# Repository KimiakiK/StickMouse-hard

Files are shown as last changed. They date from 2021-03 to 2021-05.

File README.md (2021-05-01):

# Stick Mouse
[Software](https://github.com/KimiakiK/StickMouse-soft)

# Features
- ジョイスティックと静音スイッチを備えたスティック型のマウス
- マウスポインタの移動とスクロールをジョイスティックで操作（ジョイスティック押し込みで切り替え）
- 左クリックと右クリック

# Major Components  
- STM32F042K6
- Joystick
- Kailh ミュートマイクロスイッチ

# Photos
Stick Mouse V1.1
Stick Mouse example

## PCB
- V1.1
PCB V1.1
- V1.0
PCB V1.0

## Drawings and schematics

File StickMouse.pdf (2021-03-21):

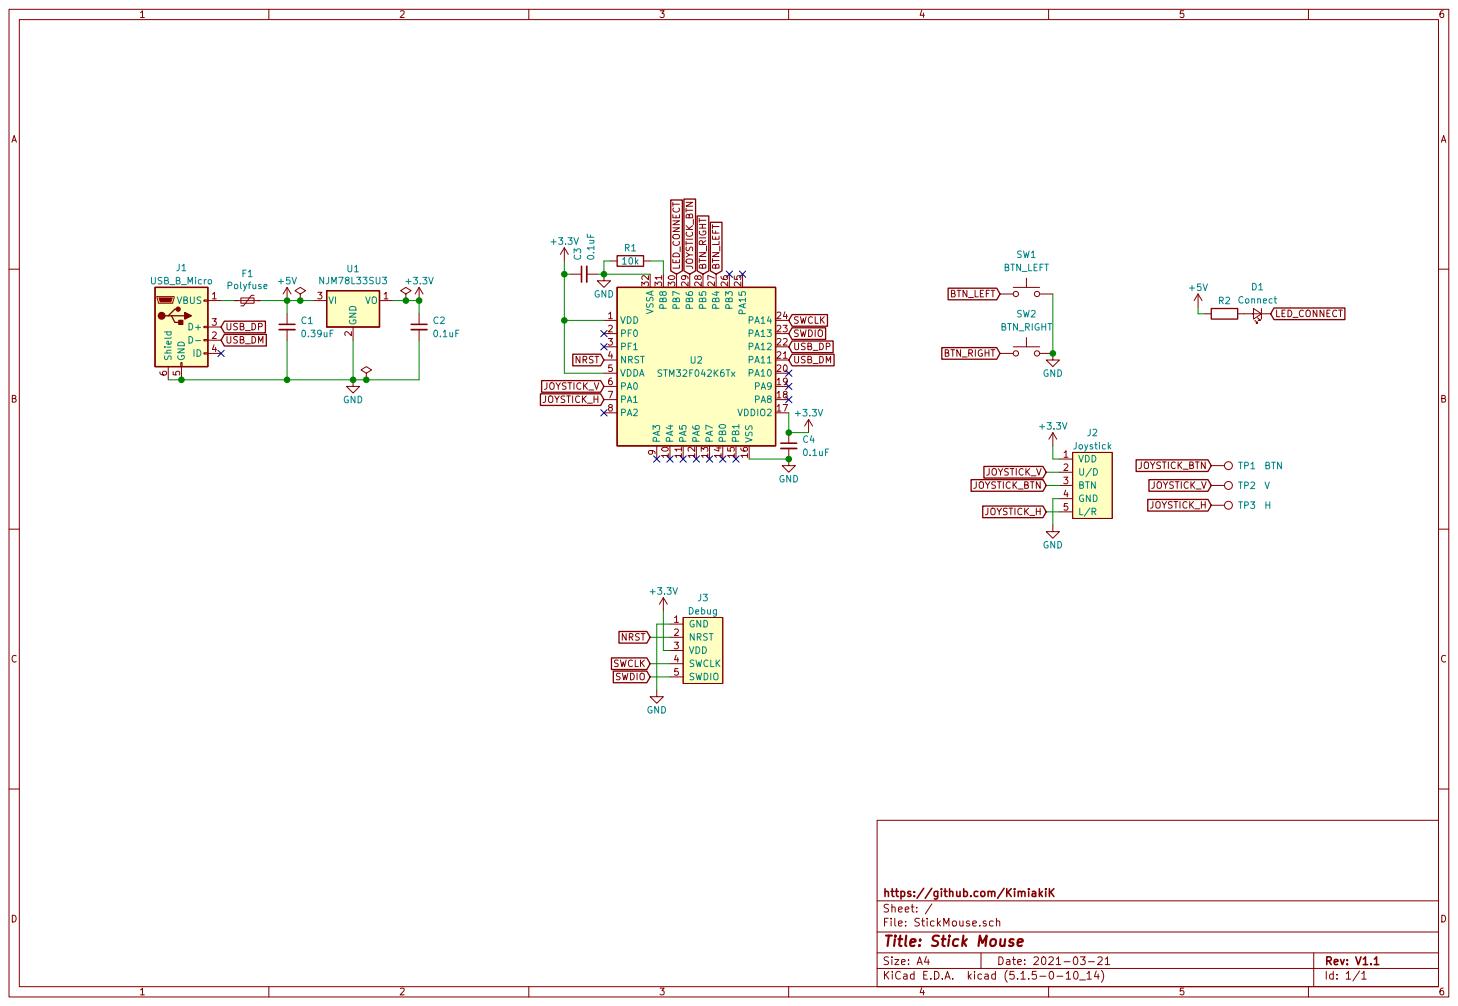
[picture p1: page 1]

File: StickMouse.sch Sheet: / https://github.com/KimiakiK

Id: 1/1 Title: Stick Mouse

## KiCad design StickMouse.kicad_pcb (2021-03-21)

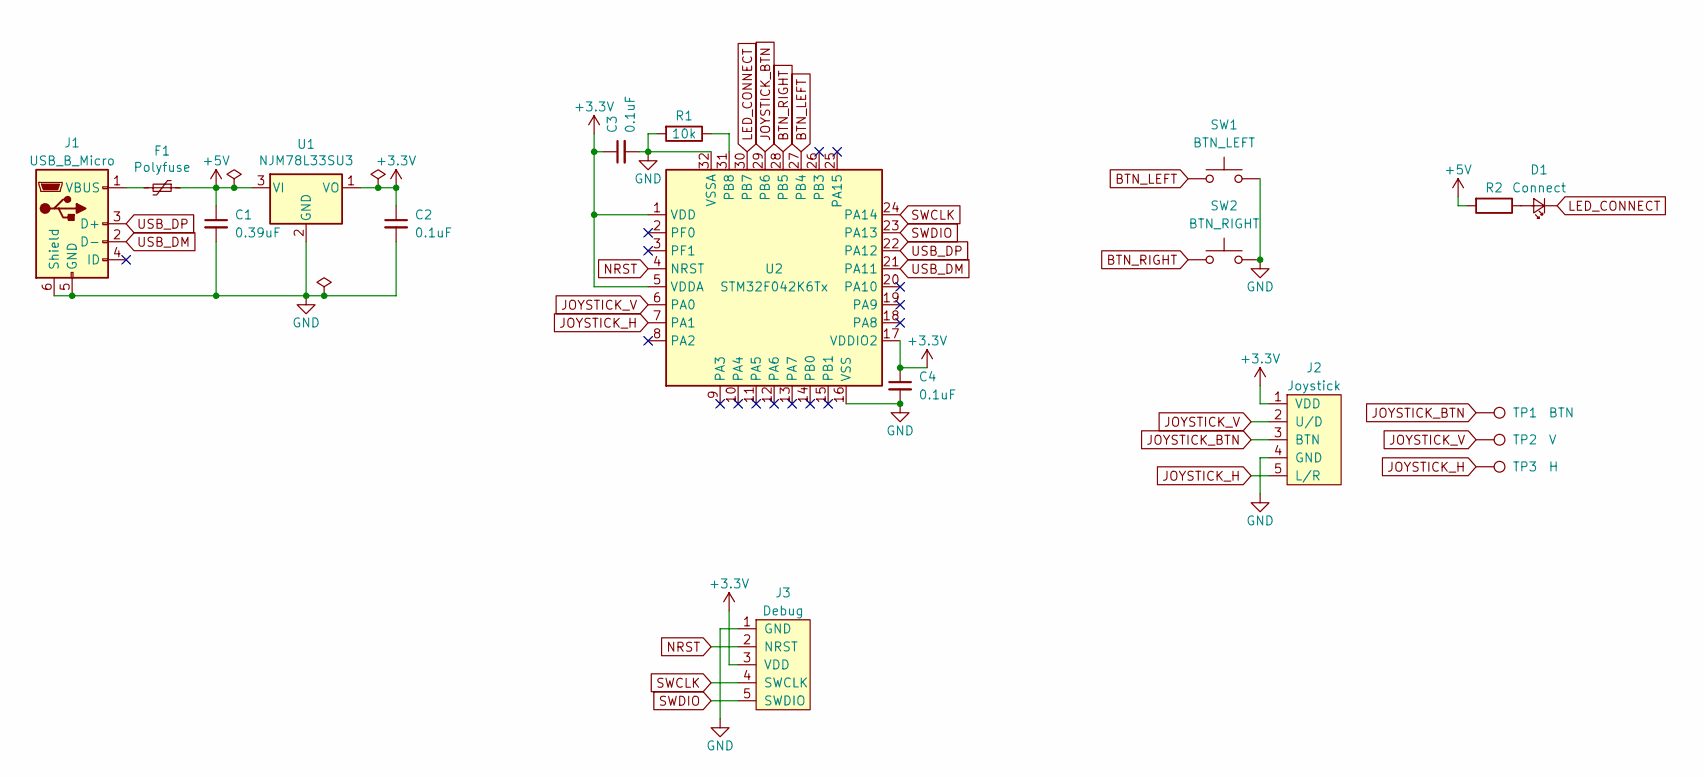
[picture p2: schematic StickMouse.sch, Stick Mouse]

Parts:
C1: 0.39uF; C_0603_1608Metric_Pad1.05x0.95mm_HandSolder
C2, C3, C4: 0.1uF; C_0603_1608Metric_Pad1.05x0.95mm_HandSolder
D1: Connect; LED_0603_1608Metric_Pad1.05x0.95mm_HandSolder
F1: Polyfuse; Fuse_1206_3216Metric_Pad1.42x1.75mm_HandSolder
J1: USB_B_Micro; ZX62-B-5PA
J2: Joystick; JoyCon_Joystick
J3: Debug; STM32_Debug_5pin
R1: 10k; R_0603_1608Metric_Pad1.05x0.95mm_HandSolder
R2: R; R_0603_1608Metric_Pad1.05x0.95mm_HandSolder
SW1: BTN_LEFT; Kailh_Mute_Switch
SW2: BTN_RIGHT; Kailh_Mute_Switch
TP1: BTN; TestPoint_Pad_1.0x1.0mm
TP2: V; TestPoint_Pad_1.0x1.0mm
TP3: H; TestPoint_Pad_1.0x1.0mm
U1: NJM78L33SU3; SOT-89-3
U2: STM32F042K6Tx; LQFP-32_7x7mm_P0.8mm_FusionPCB

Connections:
+3V3: C2.1, C3.1, C4.1, J2.1 (VDD), J3.3 (VDD), U1.1 (VO), U2.1 (VDD), U2.5 (VDDA), U2.17 (VDDIO2)
+5V: C1.1, F1.1, R2.2, U1.3 (VI)
BTN_LEFT: SW1.1, U2.27 (PB4)
BTN_RIGHT: SW2.1, U2.28 (PB5)
GND: C1.2, C2.2, C3.2, C4.2, J1.5 (GND), J1.6 (Shield), J2.4 (GND), J3.1 (GND), R1.2, SW1.2, SW2.2, U1.2 (GND), U2.16 (VSS), U2.32 (VSSA)
JOYSTICK_BTN: J2.3 (BTN), TP1.1, U2.29 (PB6)
JOYSTICK_H: J2.5 (L/R), TP3.1, U2.7 (PA1)
JOYSTICK_V: J2.2 (U/D), TP2.1, U2.6 (PA0)
LED_CONNECT: D1.1 (K), U2.30 (PB7)
NRST: J3.2 (NRST), U2.4 (NRST)
unnamed: D1.2 (A), R2.1
unnamed: F1.2, J1.1 (VBUS)
unnamed: R1.1, U2.31 (PB8)
SWCLK: J3.4 (SWCLK), U2.24 (PA14)
SWDIO: J3.5 (SWDIO), U2.23 (PA13)
USB_DM: J1.2 (D-), U2.21 (PA11)
USB_DP: J1.3 (D+), U2.22 (PA12)

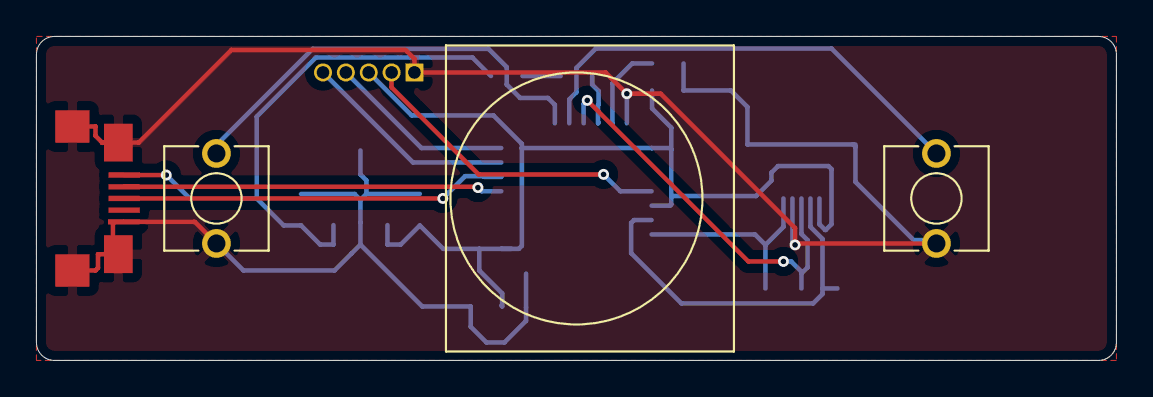
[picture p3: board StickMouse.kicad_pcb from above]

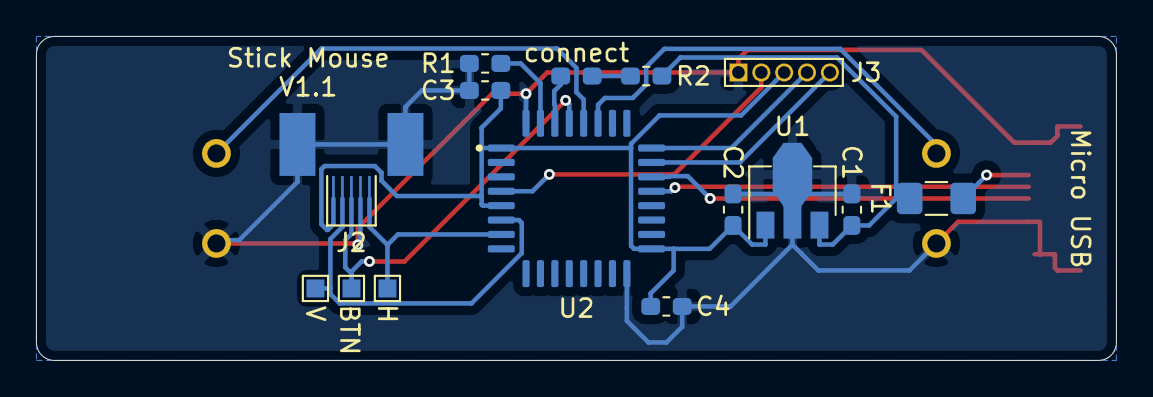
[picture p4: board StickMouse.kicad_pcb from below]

Board: 2 copper layers, 60.0 x 18.0 mm, 18 parts (14 on the bottom side), 17 nets.

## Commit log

2021-02-10 基板 V1.0
    [StickMouse-B_Cu.gbl, StickMouse-B_Mask.gbs, StickMouse-B_Paste.gbp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]
2021-03-21 基板 V1.1
    [StickMouse-B_Cu.gbl, StickMouse-B_Mask.gbs, StickMouse-B_Paste.gbp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]
